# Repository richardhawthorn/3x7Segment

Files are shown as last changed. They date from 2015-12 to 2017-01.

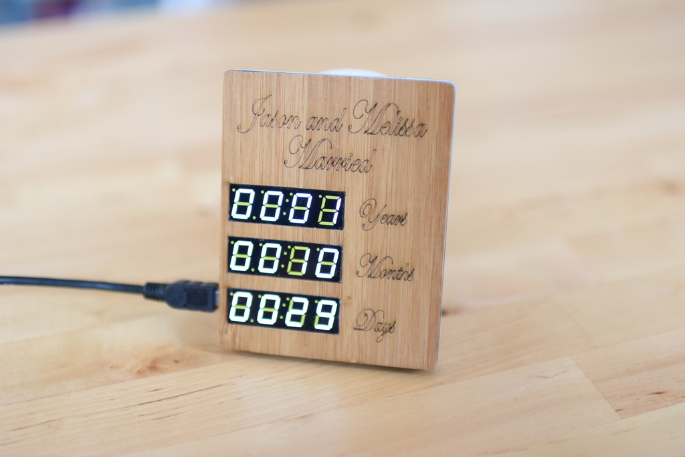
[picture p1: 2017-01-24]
images/DSC_3861.JPG

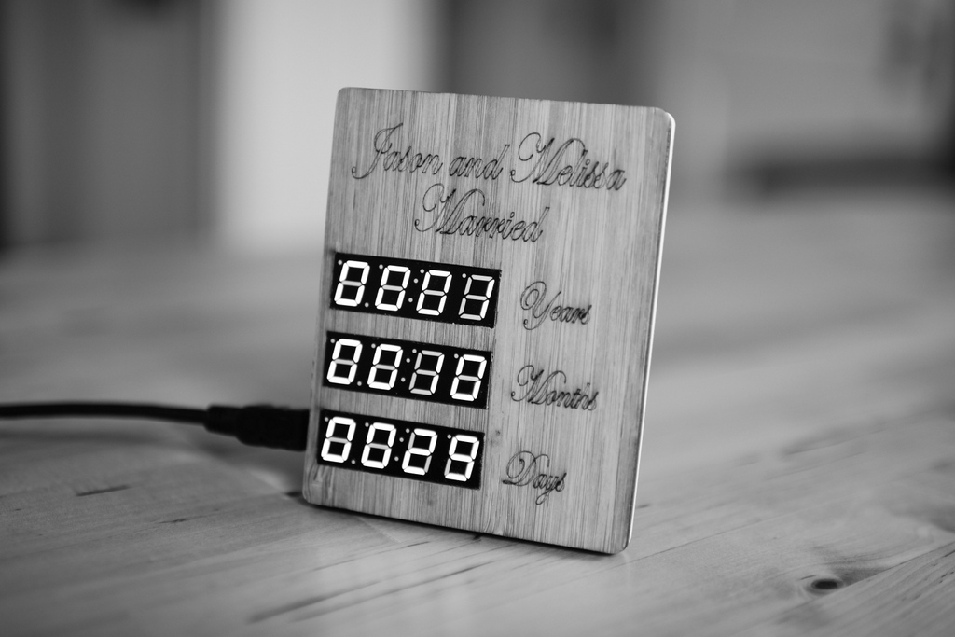
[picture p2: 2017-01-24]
images/16-DSC_3874.JPG

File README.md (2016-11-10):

### Features

- ESP8266 wifi processor
- 3 x 7 segment displays
- 3.3V operation
- Mini USB power connector
- FTDI chip and programming port

### License

This work is licensed under a Creative Commons Attribution-ShareAlike 4.0 International License.

<br />
Designed by <a xmlns:cc="http://creativecommons.org/ns#" href="http://www.richardhawthorn.com" property="cc:attributionName" rel="cc:attributionURL" target="_blank">Richard Hawthorn</a><br />
<a rel="license" href="http://creativecommons.org/licenses/by-sa/4.0/" target="_blank">View License</a>

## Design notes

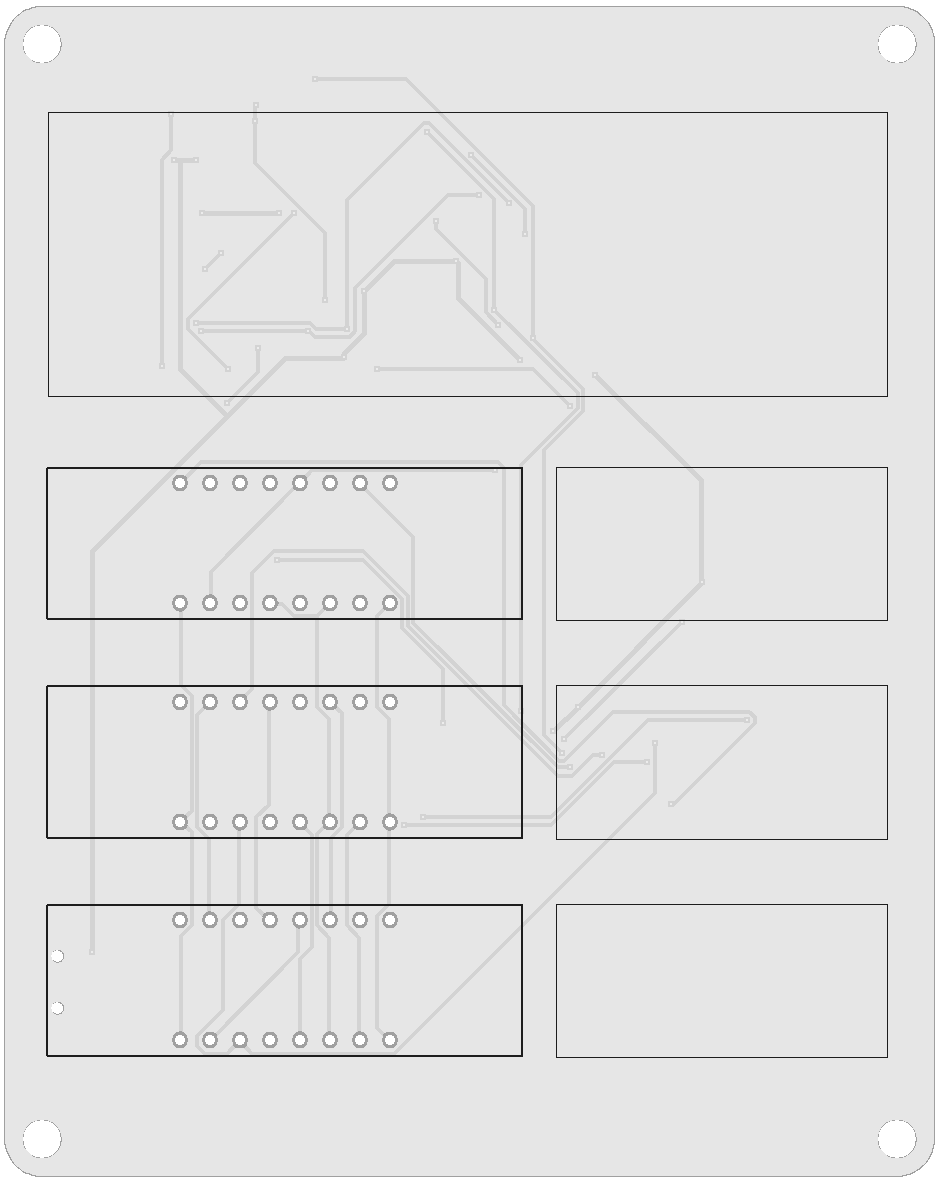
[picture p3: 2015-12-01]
images/pcb_back_v2.png

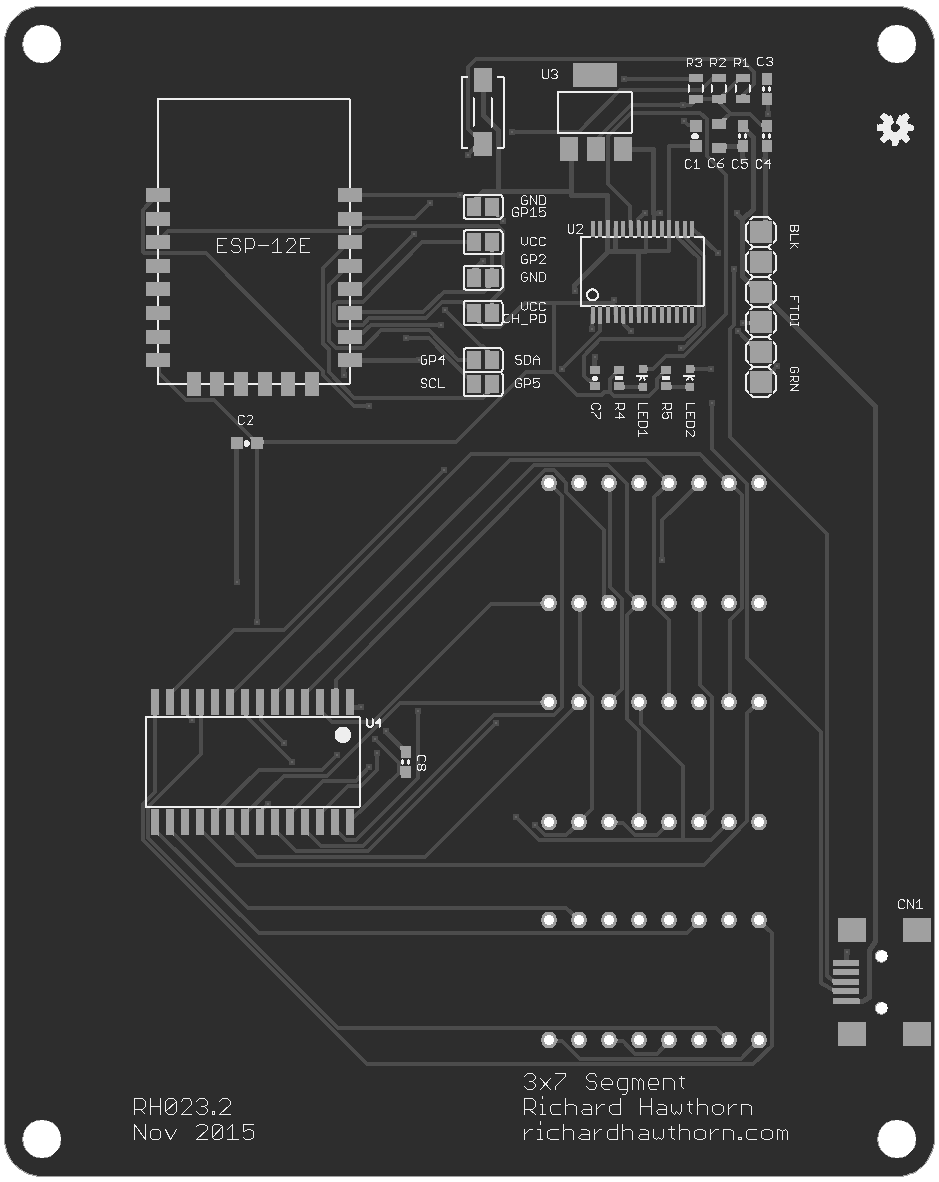
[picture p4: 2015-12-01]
images/pcb_front_v2_black.png

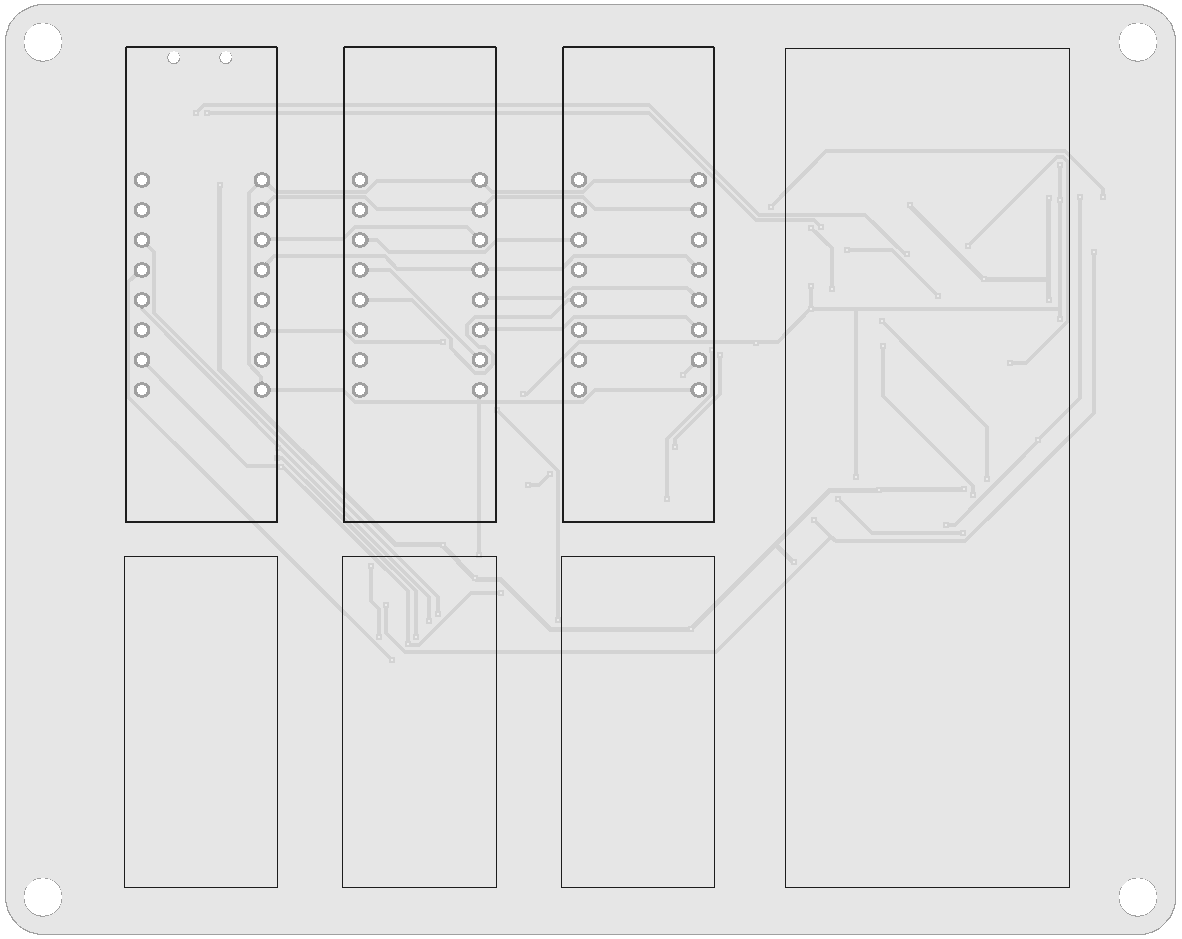
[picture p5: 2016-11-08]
images/pcb_back_v3.png

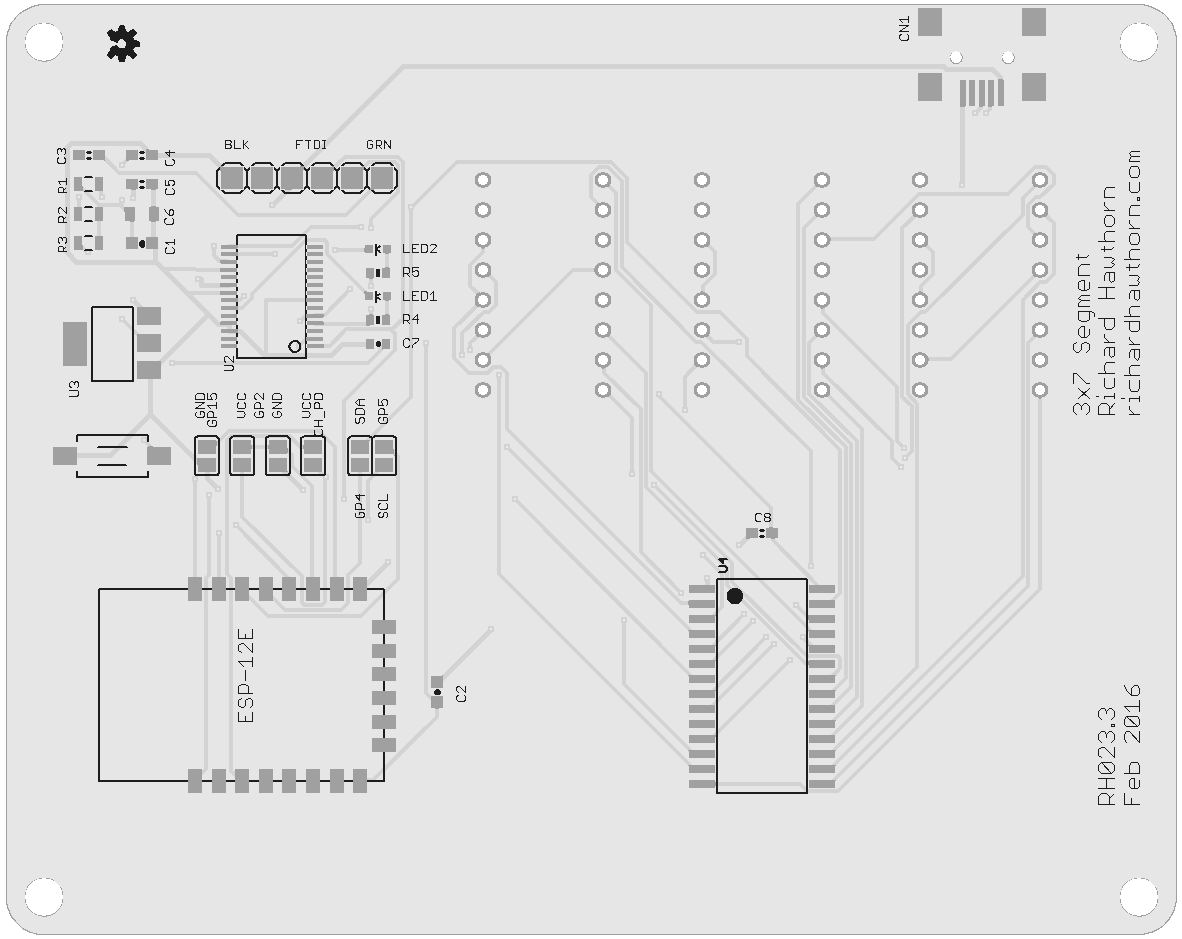
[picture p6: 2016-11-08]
images/pcb_front_v3.png

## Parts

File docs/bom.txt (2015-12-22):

Part     Value          Device 

C1       0.1uF          CAP0805-CAP 
C2       0.1uF          CAP0805-CAP 
C3       0.1uF          CAP0805-CAP 
C4       0.1uF          CAP0805-CAP 
C5       1uF            CAP0805-CAP 
C6       10uF           CAP0805-CAP 
C8       0.1uF          CAP0805-CAP 
CN1      USB            USB-MINI-B 
JP1      FTDI           PINHD-1X6 
LED3     7SEG-4DIGIT    7SEG-4DIGIT  
LED4     7SEG-4DIGIT    7SEG-4DIGIT 
LED5     7SEG-4DIGIT    7SEG-4DIGIT 
R1       4.7k           RESISTOR0805-RES 
R2       4.7k           RESISTOR0805-RES 
R3       4.7k           RESISTOR0805-RES 
S1       RESET          DTSM-3  
U1       ESP8266        ESP8266-ESP12E 
U3       REG1117        REG1117 
U4       HT16K33        HT16K33_SOP28

Future Upgrade

U2       FT232RLSSOP    FT232RLSSOP 
C7       0.1uF          CAP0805-CAP 
R4       1K             RESISTOR0402-RES 
R5       1K             RESISTOR0402-RES 
LED1     Red            LED0603 
LED2     Green          LED0603

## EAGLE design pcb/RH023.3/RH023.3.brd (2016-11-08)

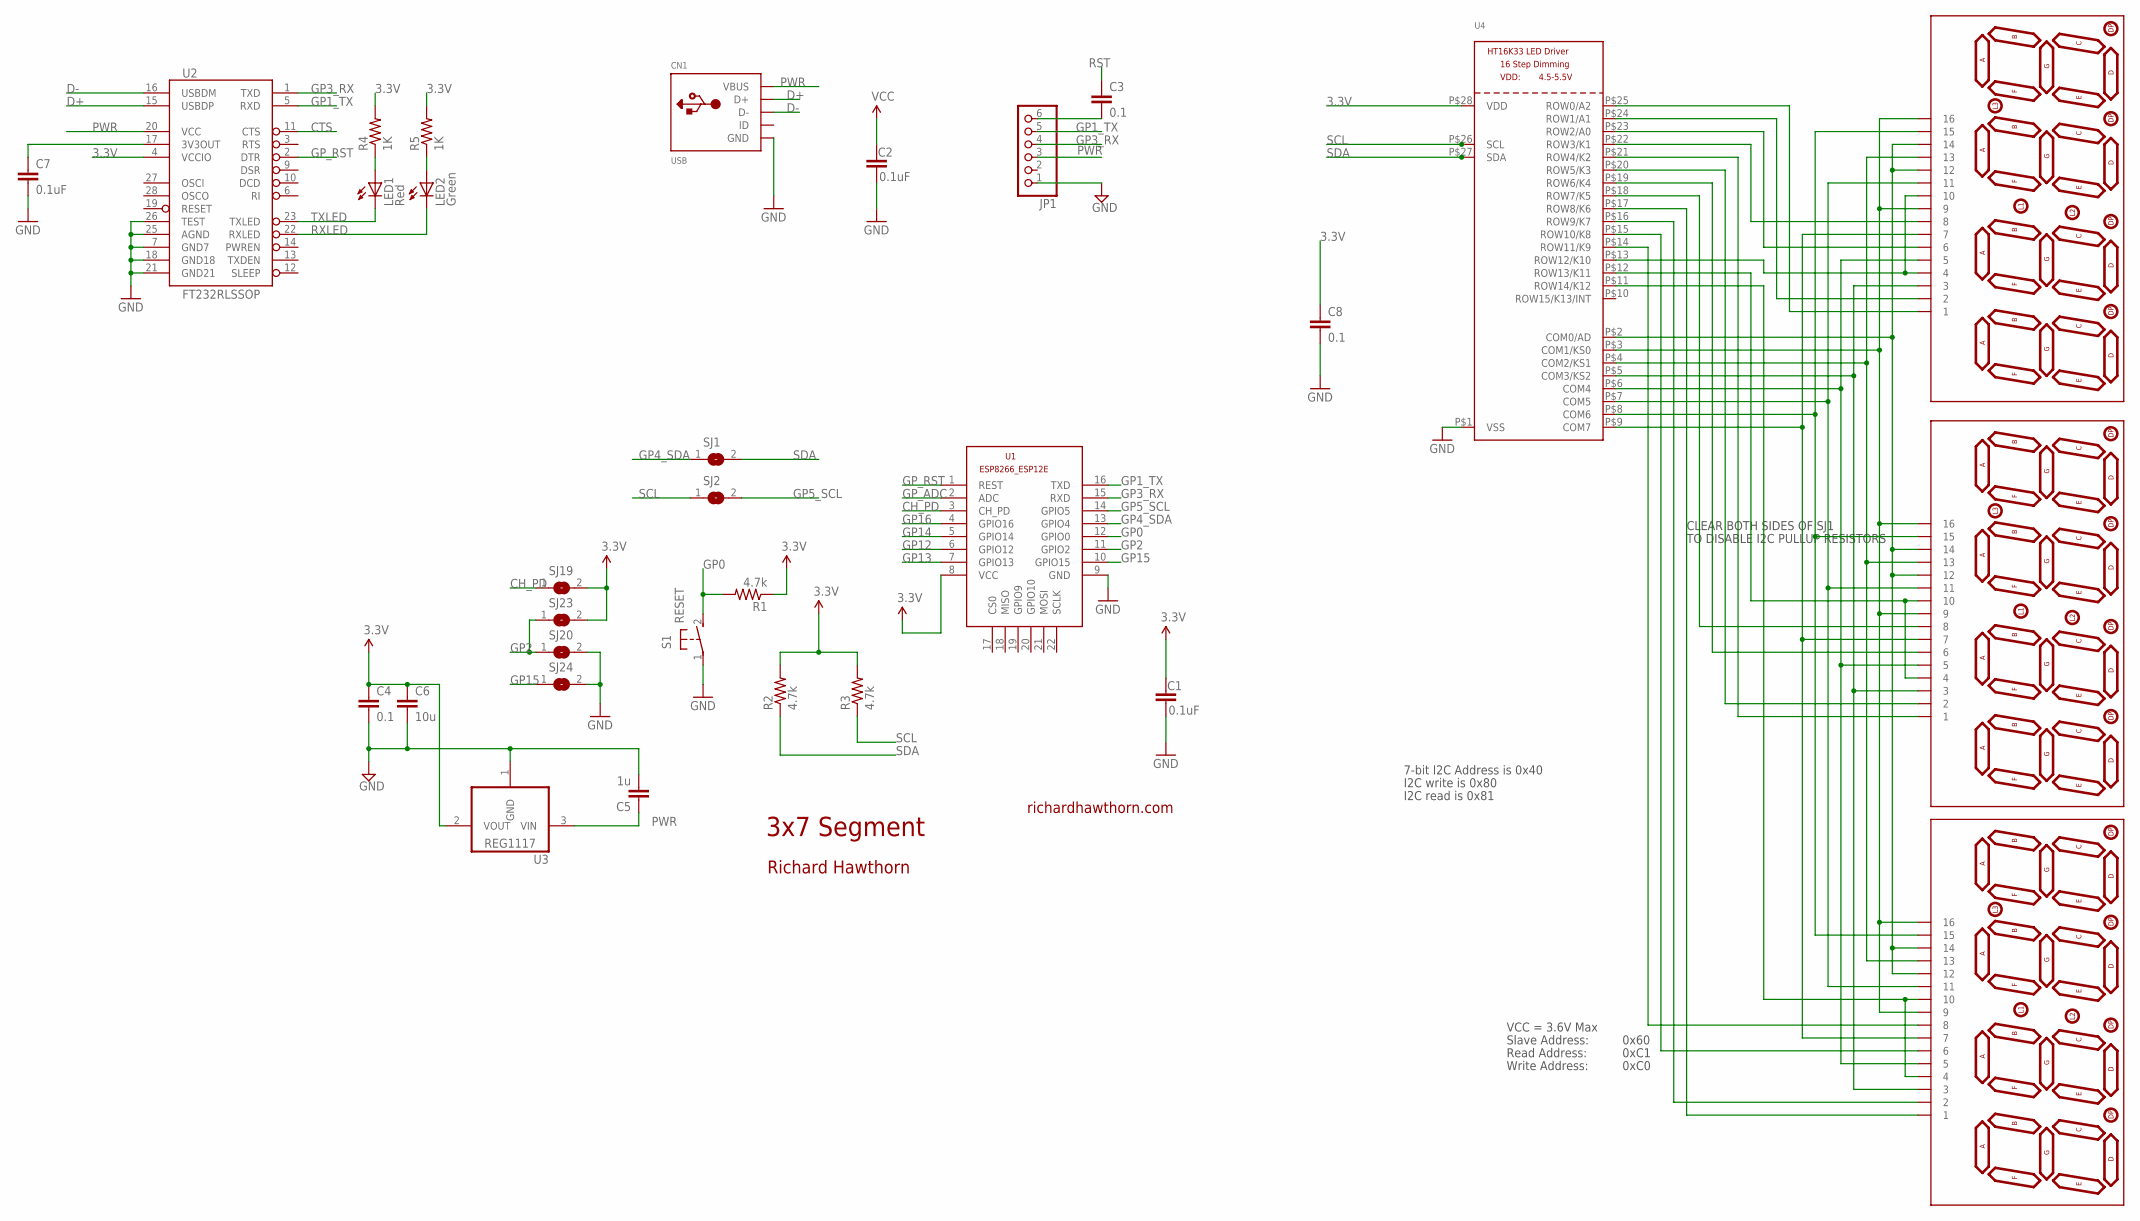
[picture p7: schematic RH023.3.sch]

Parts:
C1, C2: 0.1uF; 0603-CAP
C3, C4, C8: 0.1; 0603-CAP
C5: 1u; 0603-CAP
C6: 10u; 0805-CAP
C7: 0.1uF; 0402-CAP
CN1: USB; USB-MINIB
JP1: PINHD-1X6; 1X06
LED1: Red; LED-0603
LED2: Green; LED-0603
LED3, LED4, LED5: 7SEG-4DIGIT; SPARKFUN_7-SEGMENT-4DIGIT
R1, R2, R3: 4.7k; 0805
R4, R5: 1K; 0402-RES
S1: RESET; DTSM-3
SJ1, SJ2, SJ19, SJ20, SJ23, SJ24: SJ
U1: ESP8266-12EESP8266-ESP12E; ESP8266-ESP12E
U2: FT232RLSSOP; SSOP28DB
U3: REG1117; SOT223
U4: HT16K33_SOP28; SOP28_300MIL

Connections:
3.3V: C1.1, C2.1, C4.1, C6.1, C8.1, R1.1, R2.2, R3.2, R4.2, R5.2, SJ19.2, SJ23.2, U1.8 (VCC), U2.4 (VCCIO), U3.2 (VOUT), U4.P$28 (VDD)
3.3VOUT: C7.1, U2.17 (3V3OUT)
CH_PD: SJ19.1, U1.3 (CH_PD)
CTS: U2.11 (CTS)
D+: CN1.D+, U2.15 (USBDP)
D-: CN1.D-, U2.16 (USBDM)
GND: C1.2, C2.2, C4.2, C5.2, C6.2, C7.2, C8.2, CN1.GND, JP1.1, S1.1, SJ20.2, SJ24.2, U1.9 (GND), U2.7 (GND7), U2.18 (GND18), U2.21 (GND21), U2.25 (AGND), U2.26 (TEST), U3.1 (GND), U4.P$1 (VSS)
GP0: R1.2, S1.2, U1.12 (GPIO0)
GP1_TX: JP1.5, U1.16 (TXD), U2.5 (RXD)
GP2: SJ20.1, SJ23.1, U1.11 (GPIO2)
GP3_RX: JP1.4, U1.15 (RXD), U2.1 (TXD)
GP4_SDA: SJ1.1, U1.13 (GPIO4)
GP5_SCL: SJ2.2, U1.14 (GPIO5)
GP12: U1.6 (GPIO12)
GP13: U1.7 (GPIO13)
GP14: U1.5 (GPIO14)
GP15: SJ24.1, U1.10 (GPIO15)
GP16: U1.4 (GPIO16)
GP_ADC: U1.2 (ADC)
GP_RST: U1.1 (REST), U2.2 (DTR)
unnamed: LED3.12, LED3.14, LED4.12, LED4.14, LED5.12, LED5.14, U4.P$2 (COM0/AD)
unnamed: LED1.A, R4.1
unnamed: LED2.A, R5.1
unnamed: LED3.9, LED3.16, LED4.9, LED4.16, LED5.9, LED5.16, U4.P$3 (COM1/KS0)
unnamed: LED3.13, LED4.13, LED5.13, U4.P$4 (COM2/KS1)
unnamed: LED3.3, LED4.3, LED5.3, U4.P$5 (COM3/KS2)
unnamed: LED3.5, LED4.5, LED5.5, U4.P$6 (COM4)
unnamed: LED3.11, LED4.11, LED5.11, U4.P$7 (COM5)
unnamed: LED3.15, LED4.15, LED5.15, U4.P$8 (COM6)
unnamed: LED3.7, LED4.7, LED5.7, U4.P$9 (COM7)
unnamed: LED3.1, U4.P$25 (ROW0/A2)
unnamed: LED3.2, U4.P$24 (ROW1/A1)
unnamed: LED3.6, U4.P$23 (ROW2/A0)
unnamed: LED3.8, U4.P$22 (ROW3/K1)
unnamed: LED4.1, U4.P$21 (ROW4/K2)
unnamed: LED4.2, U4.P$20 (ROW5/K3)
unnamed: LED4.6, U4.P$19 (ROW6/K4)
unnamed: LED4.8, U4.P$18 (ROW7/K5)
unnamed: LED5.1, U4.P$17 (ROW8/K6)
unnamed: C3.2, JP1.6
unnamed: LED5.2, U4.P$16 (ROW9/K7)
unnamed: LED5.6, U4.P$15 (ROW10/K8)
unnamed: LED5.8, U4.P$14 (ROW11/K9)
unnamed: LED3.4, LED3.10, U4.P$13 (ROW12/K10)
unnamed: LED4.4, LED4.10, U4.P$12 (ROW13/K11)
unnamed: LED5.4, LED5.10, U4.P$11 (ROW14/K12)
PWR: C5.1, CN1.VBUS, JP1.3, U2.20 (VCC), U3.3 (VIN)
RST: C3.1
RXLED: LED2.C, U2.22 (RXLED)
SCL: R3.1, SJ2.1, U4.P$26 (SCL)
SDA: R2.1, SJ1.2, U4.P$27 (SDA)
TXLED: LED1.C, U2.23 (TXLED)

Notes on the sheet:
3x7 Segment
richardhawthorn.com
Richard Hawthorn
CLEAR BOTH SIDES OF SJ1
TO DISABLE I2C PULLUP RESISTORS
7-bit I2C Address is 0x40
I2C write is 0x80
I2C read is 0x81
VCC = 3.6V Max
Read Address:
Write Address:
Slave Address:
0x60
0xC1
0xC0

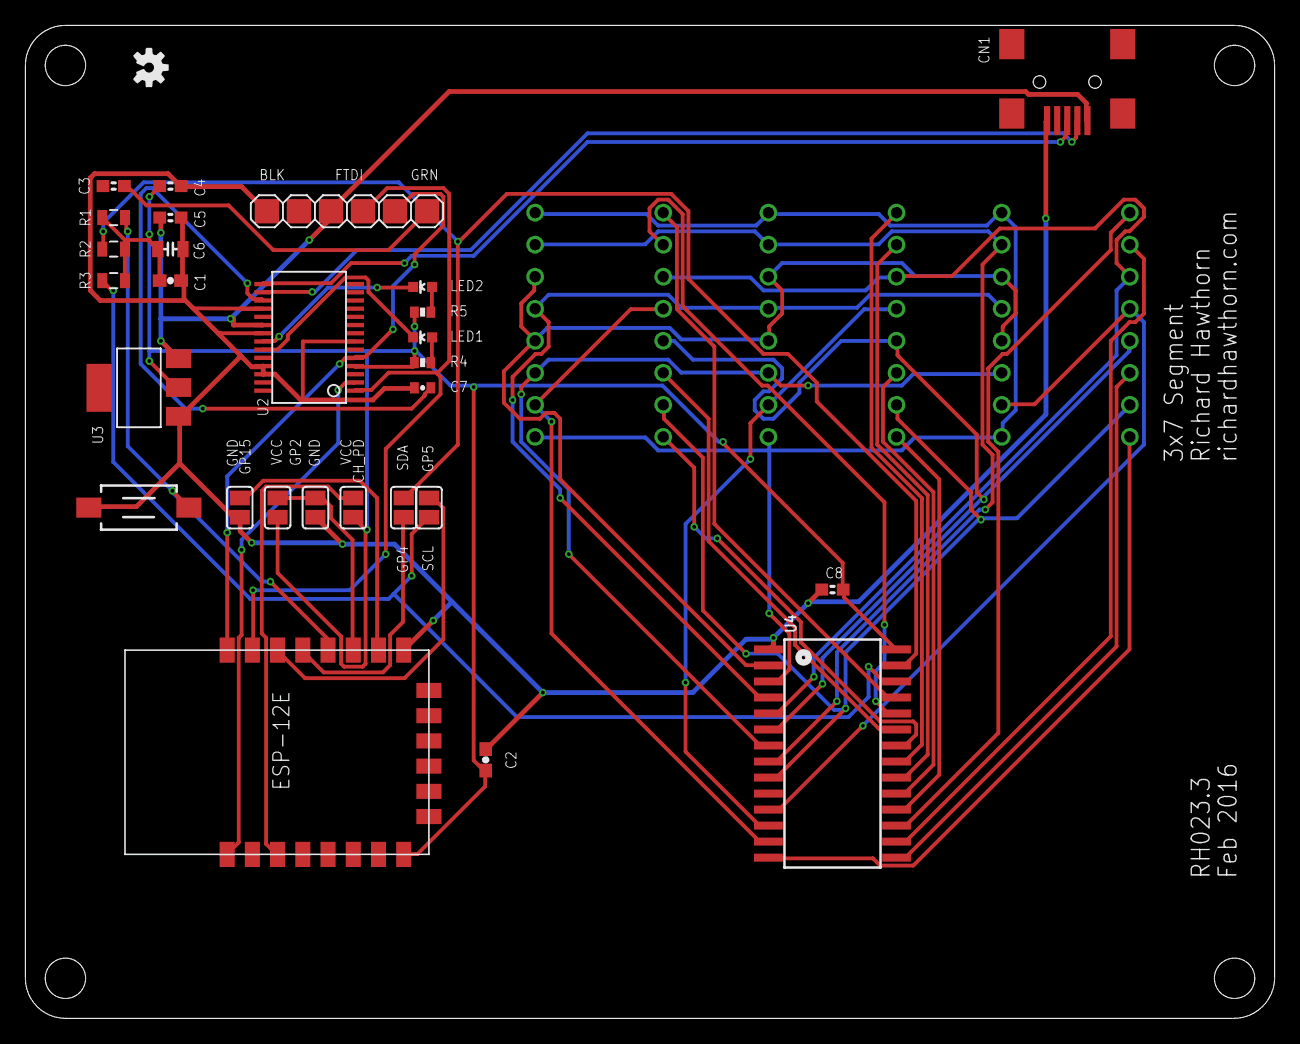
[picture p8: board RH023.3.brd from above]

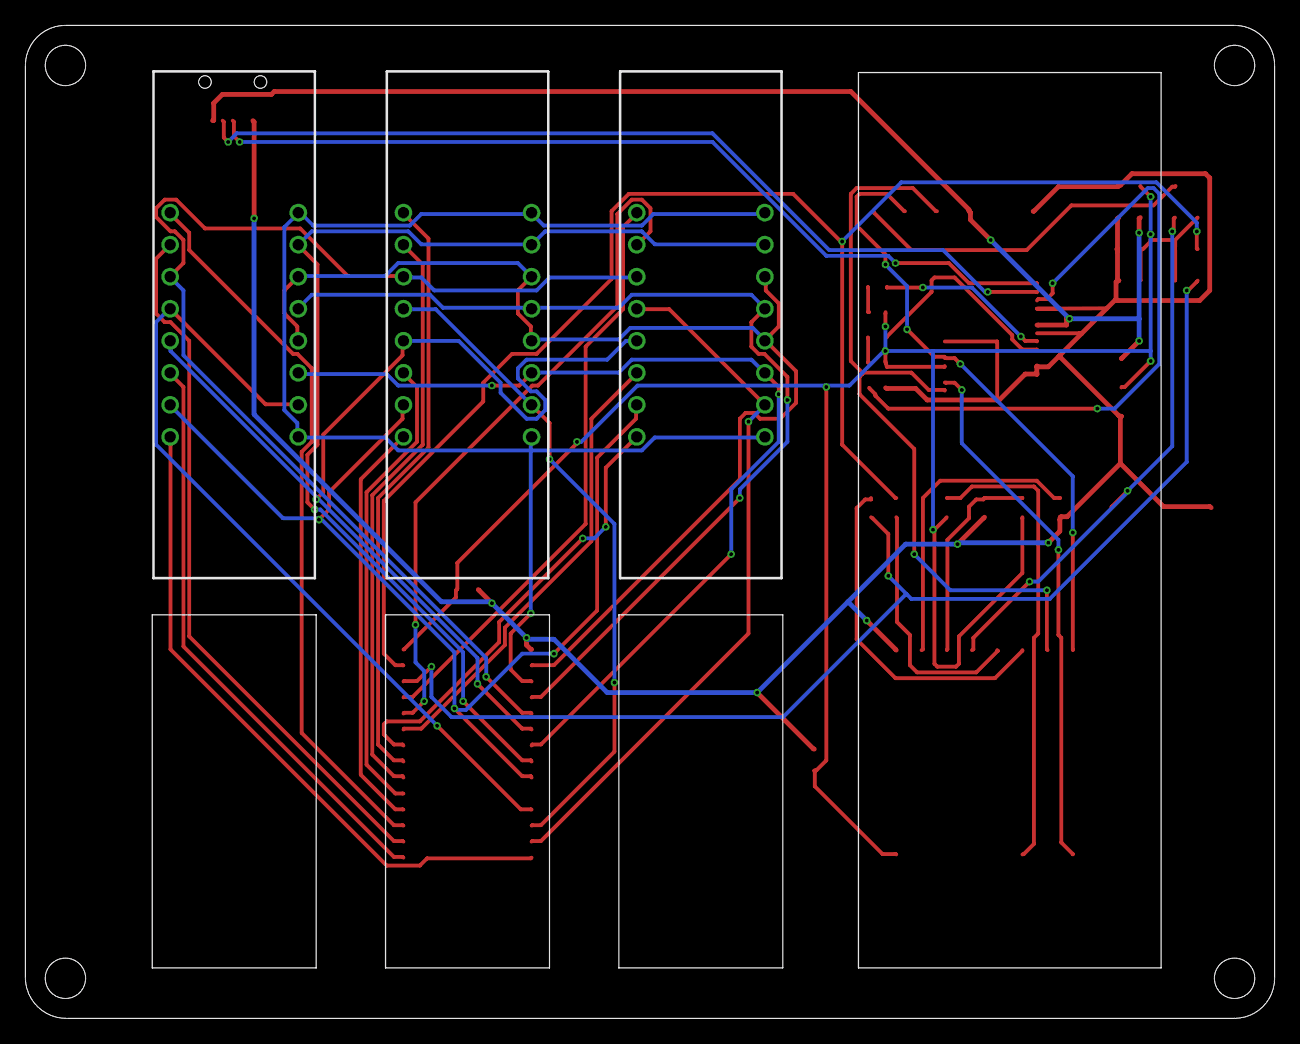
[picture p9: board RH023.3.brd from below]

Board: 2 copper layers, 99.1 x 78.7 mm, 32 parts (3 on the bottom side), 45 nets.

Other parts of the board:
U$3: OSHW-LOGO-S

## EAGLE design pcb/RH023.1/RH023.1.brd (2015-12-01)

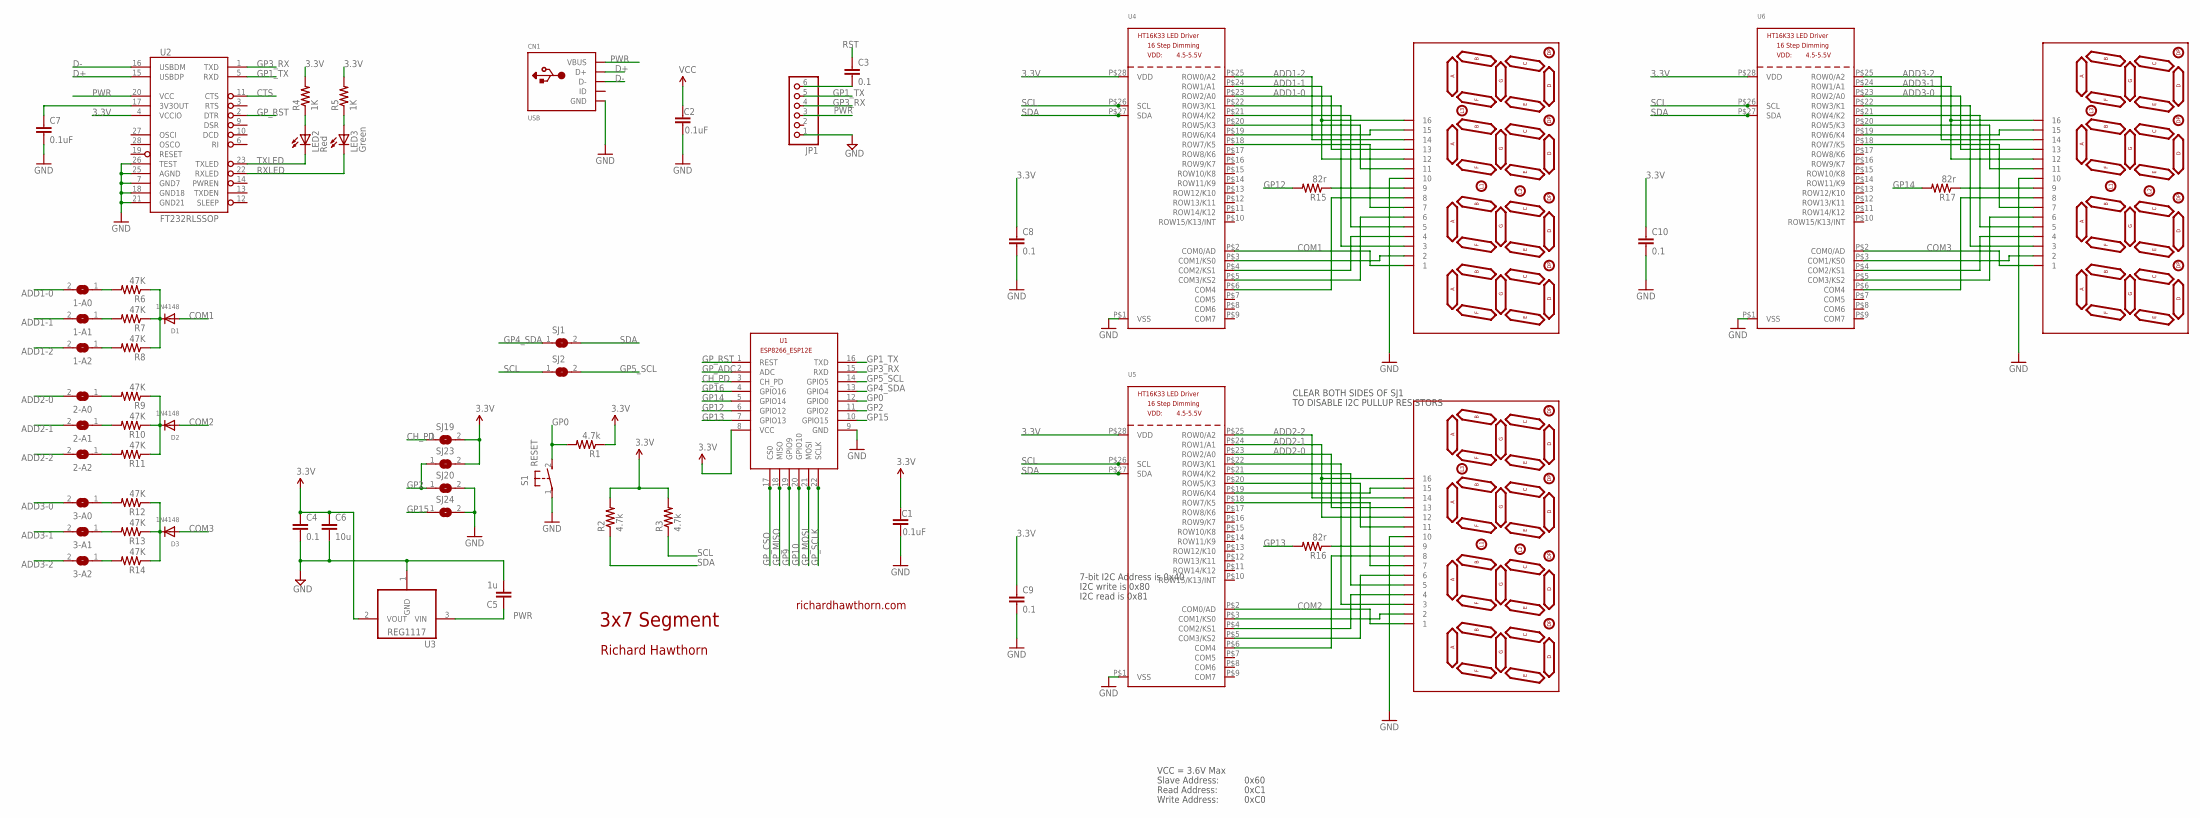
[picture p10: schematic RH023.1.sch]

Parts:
1-A0, 1-A1, 1-A2, 2-A0, 2-A1, 2-A2, 3-A0, 3-A1, 3-A2: SOLDERJUMPERREFLOW_NOPASTE; SOLDERJUMPER_REFLOW_NOPASTE
C1, C2: 0.1uF; 0603-CAP
C3, C4, C8, C9, C10: 0.1; 0603-CAP
C5: 1u; 0603-CAP
C6: 10u; 0805-CAP
C7: 0.1uF; 0402-CAP
CN1: USB; USB-MINIB
D1, D2, D3: 1N4148; SOD-323F
JP1: PINHD-1X6; 1X06
LED1, LED4, LED5: 7SEG-4DIGIT; SPARKFUN_7-SEGMENT-4DIGIT
LED2: Red; LED-0603
LED3: Green; LED-0603
R1, R2, R3: 4.7k; 0805
R4, R5: 1K; 0402-RES
R6, R7, R8, R9, R10, R11, R12, R13, R14: 47K; R0805
R15, R16, R17: 82r; 0805
S1: RESET; DTSM-3
SJ1, SJ2, SJ19, SJ20, SJ23, SJ24: SJ
U1: ESP8266-12EESP8266-ESP12E; ESP8266-ESP12E
U2: FT232RLSSOP; SSOP28DB
U3: REG1117; SOT223
U4, U5, U6: HT16K33_SOP28; SOP28_300MIL

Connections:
3.3V: C1.1, C2.1, C4.1, C6.1, C8.1, C9.1, C10.1, R1.1, R2.2, R3.2, R4.2, R5.2, SJ19.2, SJ23.2, U1.8 (VCC), U2.4 (VCCIO), U3.2 (VOUT), U4.P$28 (VDD), U5.P$28 (VDD), U6.P$28 (VDD)
3.3VOUT: C7.1, U2.17 (3V3OUT)
ADD1-0: 1-A0.2, LED1.13, U4.P$23 (ROW2/A0)
ADD1-1: 1-A1.2, LED1.12, LED1.16, U4.P$24 (ROW1/A1)
ADD1-2: 1-A2.2, LED1.14, U4.P$25 (ROW0/A2)
ADD2-0: 2-A0.2, LED4.13, U5.P$23 (ROW2/A0)
ADD2-1: 2-A1.2, LED4.12, LED4.16, U5.P$24 (ROW1/A1)
ADD2-2: 2-A2.2, LED4.14, U5.P$25 (ROW0/A2)
ADD3-0: 3-A0.2, LED5.13, U6.P$23 (ROW2/A0)
ADD3-1: 3-A1.2, LED5.12, LED5.16, U6.P$24 (ROW1/A1)
ADD3-2: 3-A2.2, LED5.14, U6.P$25 (ROW0/A2)
CH_PD: SJ19.1, U1.3 (CH_PD)
COM1: D1.A, LED1.1, U4.P$2 (COM0/AD)
COM2: D2.A, LED4.1, U5.P$2 (COM0/AD)
COM3: D3.A, LED5.1, U6.P$2 (COM0/AD)
CTS: U2.11 (CTS)
D+: CN1.D+, U2.15 (USBDP)
D-: CN1.D-, U2.16 (USBDM)
GND: C1.2, C2.2, C4.2, C5.2, C6.2, C7.2, C8.2, C9.2, C10.2, CN1.GND, JP1.1, LED1.10, LED4.10, LED5.10, S1.1, SJ20.2, SJ24.2, U1.9 (GND), U2.7 (GND7), U2.18 (GND18), U2.21 (GND21), U2.25 (AGND), U2.26 (TEST), U3.1 (GND), U4.P$1 (VSS), U5.P$1 (VSS), U6.P$1 (VSS)
GP0: R1.2, S1.2, U1.12 (GPIO0)
GP1_TX: JP1.5, U1.16 (TXD), U2.5 (RXD)
GP2: SJ20.1, SJ23.1, U1.11 (GPIO2)
GP3_RX: JP1.4, U1.15 (RXD), U2.1 (TXD)
GP4_SDA: SJ1.1, U1.13 (GPIO4)
GP5_SCL: SJ2.2, U1.14 (GPIO5)
GP9: U1.19 (GPIO9)
GP10: U1.20 (GPIO10)
GP12: R15.2, U1.6 (GPIO12)
GP13: R16.2, U1.7 (GPIO13)
GP14: R17.2, U1.5 (GPIO14)
GP15: SJ24.1, U1.10 (GPIO15)
GP16: U1.4 (GPIO16)
GP_ADC: U1.2 (ADC)
GP_CSO: U1.17 (CS0)
GP_MISO: U1.18 (MISO)
GP_MOSI: U1.21 (MOSI)
GP_RST: U1.1 (REST), U2.2 (DTR)
GP_SCLK: U1.22 (SCLK)
unnamed: LED1.9, R15.1
unnamed: LED2.A, R4.1
unnamed: LED3.A, R5.1
unnamed: 2-A1.1, R10.2
unnamed: 1-A0.1, R6.2
unnamed: LED1.11, U4.P$20 (ROW5/K3)
unnamed: LED1.2, U4.P$3 (COM1/KS0)
unnamed: LED1.4, U4.P$4 (COM2/KS1)
unnamed: LED1.6, U4.P$5 (COM3/KS2)
unnamed: LED1.8, U4.P$6 (COM4)
unnamed: LED1.3, U4.P$22 (ROW3/K1)
unnamed: LED1.5, U4.P$21 (ROW4/K2)
unnamed: 2-A0.1, R9.2
unnamed: LED1.7, U4.P$18 (ROW7/K5)
unnamed: LED1.15, U4.P$19 (ROW6/K4)
unnamed: D2.C, R9.1, R10.1, R11.1
unnamed: D1.C, R6.1, R7.1, R8.1
unnamed: 1-A2.1, R8.2
unnamed: 1-A1.1, R7.2
unnamed: C3.2, JP1.6
unnamed: 2-A2.1, R11.2
unnamed: 3-A1.1, R13.2
unnamed: 3-A0.1, R12.2
unnamed: D3.C, R12.1, R13.1, R14.1
unnamed: 3-A2.1, R14.2
unnamed: LED4.2, U5.P$3 (COM1/KS0)
unnamed: LED4.4, U5.P$4 (COM2/KS1)
unnamed: LED4.6, U5.P$5 (COM3/KS2)
unnamed: LED4.8, U5.P$6 (COM4)
unnamed: LED4.3, U5.P$22 (ROW3/K1)
unnamed: LED4.5, U5.P$21 (ROW4/K2)
unnamed: LED4.15, U5.P$19 (ROW6/K4)
unnamed: LED4.11, U5.P$20 (ROW5/K3)
unnamed: LED4.7, U5.P$18 (ROW7/K5)
unnamed: LED4.9, R16.1
unnamed: LED5.2, U6.P$3 (COM1/KS0)
unnamed: LED5.4, U6.P$4 (COM2/KS1)
unnamed: LED5.6, U6.P$5 (COM3/KS2)
unnamed: LED5.8, U6.P$6 (COM4)
unnamed: LED5.3, U6.P$22 (ROW3/K1)
unnamed: LED5.5, U6.P$21 (ROW4/K2)
unnamed: LED5.15, U6.P$19 (ROW6/K4)
unnamed: LED5.11, U6.P$20 (ROW5/K3)
unnamed: LED5.7, U6.P$18 (ROW7/K5)
unnamed: LED5.9, R17.1
PWR: C5.1, CN1.VBUS, JP1.3, U2.20 (VCC), U3.3 (VIN)
RST: C3.1
RXLED: LED3.C, U2.22 (RXLED)
SCL: R3.1, SJ2.1, U4.P$26 (SCL), U5.P$26 (SCL), U6.P$26 (SCL)
SDA: R2.1, SJ1.2, U4.P$27 (SDA), U5.P$27 (SDA), U6.P$27 (SDA)
TXLED: LED2.C, U2.23 (TXLED)

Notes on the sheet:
3x7 Segment
richardhawthorn.com
Richard Hawthorn
CLEAR BOTH SIDES OF SJ1
TO DISABLE I2C PULLUP RESISTORS
7-bit I2C Address is 0x40
I2C write is 0x80
I2C read is 0x81
VCC = 3.6V Max
Read Address:
Write Address:
Slave Address:
0x60
0xC1
0xC0

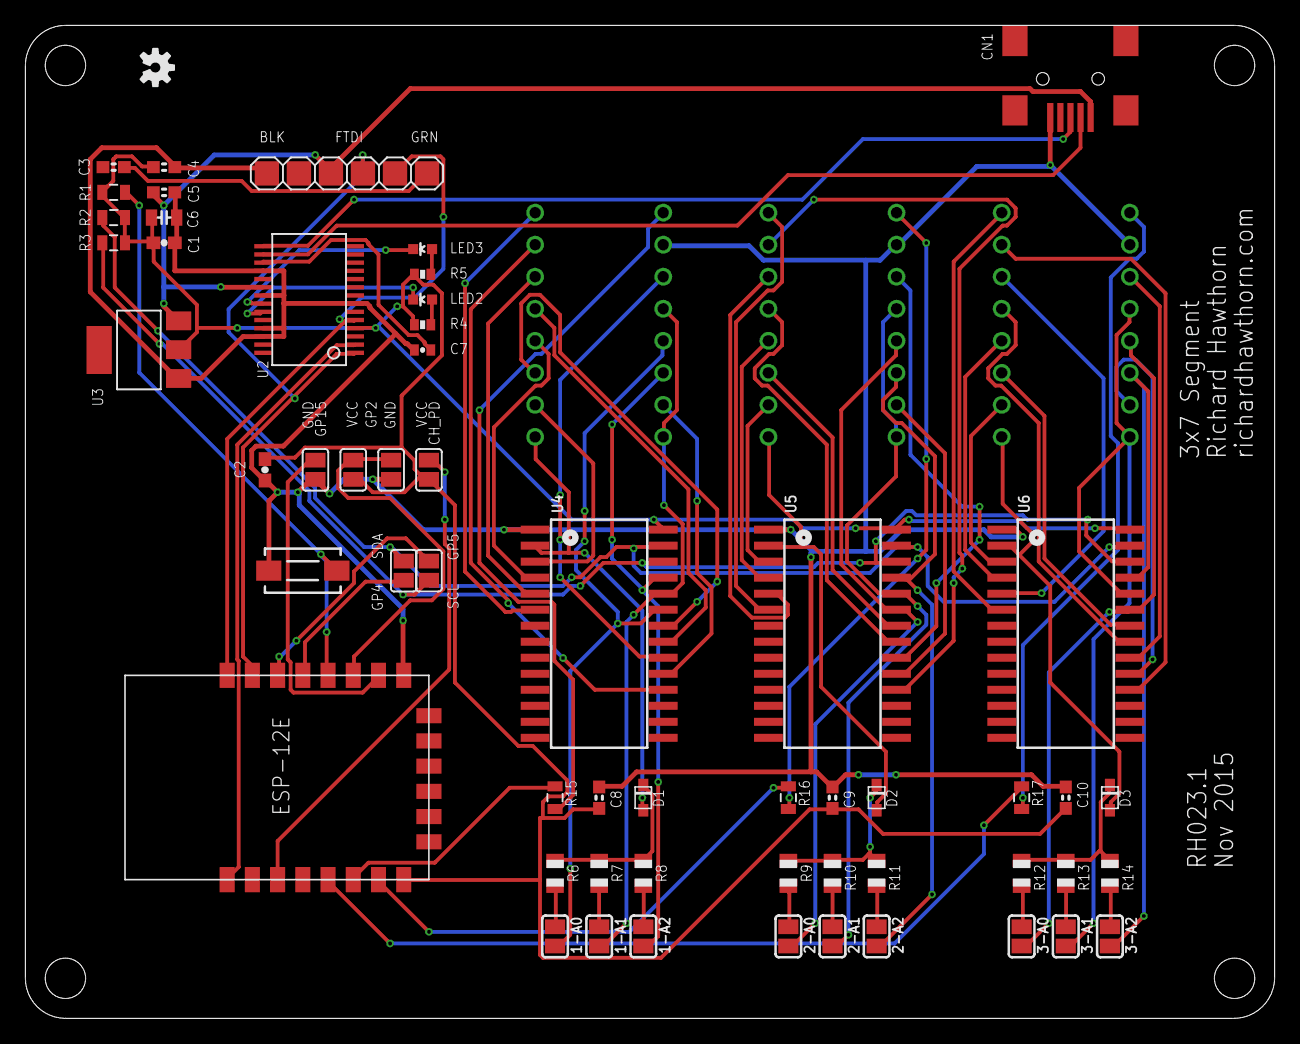
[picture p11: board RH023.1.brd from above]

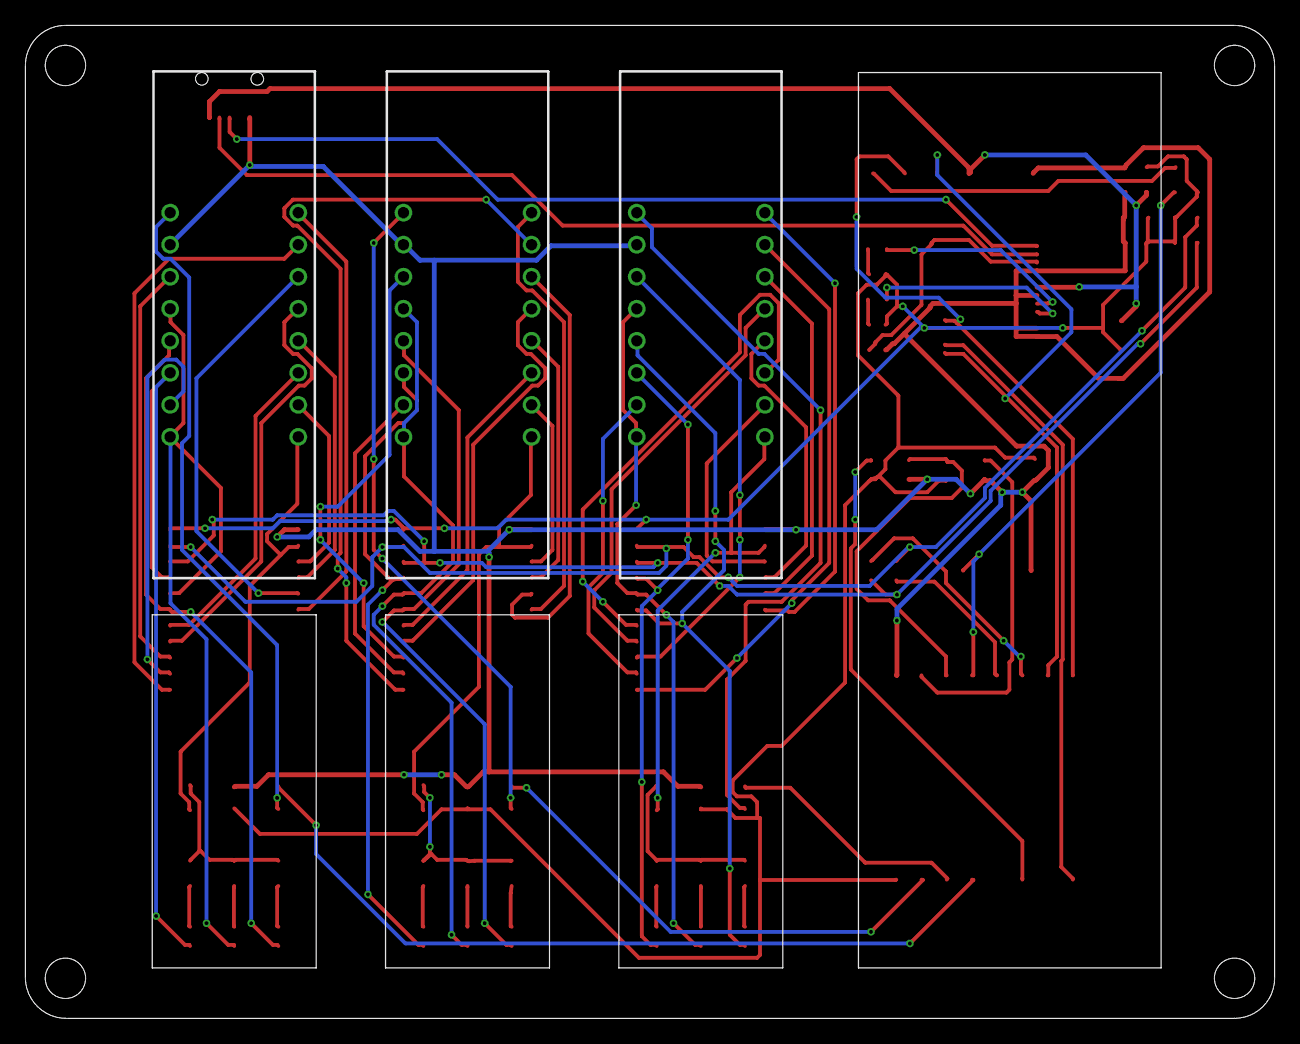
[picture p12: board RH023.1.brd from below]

Board: 2 copper layers, 99.1 x 78.7 mm, 60 parts (3 on the bottom side), 79 nets.

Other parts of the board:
U$3: OSHW-LOGO-S

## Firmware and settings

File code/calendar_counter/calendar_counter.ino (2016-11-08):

/*
 *  This sketch displays the difference between two dates on 3 x 7 segment led screens
 *
 */

#include <ESP8266WiFi.h>

#include <Wire.h>
#include <TimeLib.h>
#include "Adafruit_LEDBackpack.h"
#include "Adafruit_GFX.h"

Adafruit_LEDBackpack matrix = Adafruit_LEDBackpack();

// *******************************************************
//     Setup
// *******************************************************

const char* ssid     = "wifi_ssid";
const char* password = "wifi_password";
String compare_date = "2016-06-18";
int minutes_between_refresh = 30;

// *******************************************************
// *******************************************************

const char* host = "www.codenamefish.co.uk";
int sleep_minutes = 1;


void displayCharacter(int offset, int character, int number){

  offset = offset + 4 - character;
  
  if (number == 0){
    matrix.displaybuffer[0] |= 0x0001 << offset;
    matrix.displaybuffer[1] |= 0x0001 << offset;
    matrix.displaybuffer[2] |= 0x0001 << offset;
    matrix.displaybuffer[3] |= 0x0001 << offset;
    matrix.displaybuffer[4] |= 0x0001 << offset;
    matrix.displaybuffer[5] |= 0x0001 << offset;
  }

  if (number == 1){
    matrix.displaybuffer[4] |= 0x0001 << offset;
    matrix.displaybuffer[5] |= 0x0001 << offset;
  }

  if (number == 2){
    matrix.displaybuffer[0] |= 0x0001 << offset;
    matrix.displaybuffer[1] |= 0x0001 << offset;
    matrix.displaybuffer[3] |= 0x0001 << offset;
    matrix.displaybuffer[4] |= 0x0001 << offset;
    matrix.displaybuffer[6] |= 0x0001 << offset;
  }

  if (number == 3){
    matrix.displaybuffer[0] |= 0x0001 << offset;
    matrix.displaybuffer[3] |= 0x0001 << offset;
    matrix.displaybuffer[4] |= 0x0001 << offset;
    matrix.displaybuffer[5] |= 0x0001 << offset;
    matrix.displaybuffer[6] |= 0x0001 << offset;
  }

  if (number == 4){
    matrix.displaybuffer[2] |= 0x0001 << offset;
    matrix.displaybuffer[4] |= 0x0001 << offset;
    matrix.displaybuffer[5] |= 0x0001 << offset;
    matrix.displaybuffer[6] |= 0x0001 << offset;
  }

  if (number == 5){
    matrix.displaybuffer[0] |= 0x0001 << offset;
    matrix.displaybuffer[2] |= 0x0001 << offset;
    matrix.displaybuffer[3] |= 0x0001 << offset;
    matrix.displaybuffer[5] |= 0x0001 << offset;
    matrix.displaybuffer[6] |= 0x0001 << offset;
  }

  if (number == 6){
    matrix.displaybuffer[0] |= 0x0001 << offset;
    matrix.displaybuffer[1] |= 0x0001 << offset;
    matrix.displaybuffer[2] |= 0x0001 << offset;
    matrix.displaybuffer[3] |= 0x0001 << offset;
    matrix.displaybuffer[5] |= 0x0001 << offset;
    matrix.displaybuffer[6] |= 0x0001 << offset;
  }

  if (number == 7){
    matrix.displaybuffer[3] |= 0x0001 << offset;
    matrix.displaybuffer[4] |= 0x0001 << offset;
    matrix.displaybuffer[5] |= 0x0001 << offset;
  }

  if (number == 8){
    matrix.displaybuffer[0] |= 0x0001 << offset;
    matrix.displaybuffer[1] |= 0x0001 << offset;
    matrix.displaybuffer[2] |= 0x0001 << offset;
    matrix.displaybuffer[3] |= 0x0001 << offset;
    matrix.displaybuffer[4] |= 0x0001 << offset;
    matrix.displaybuffer[5] |= 0x0001 << offset;
    matrix.displaybuffer[6] |= 0x0001 << offset;
  }

  if (number == 9){
    matrix.displaybuffer[0] |= 0x0001 << offset;
    matrix.displaybuffer[2] |= 0x0001 << offset;
    matrix.displaybuffer[3] |= 0x0001 << offset;
    matrix.displaybuffer[4] |= 0x0001 << offset;
    matrix.displaybuffer[5] |= 0x0001 << offset;
    matrix.displaybuffer[6] |= 0x0001 << offset;
  }

}


void displayNumber(int screen, int number){

  int offset = (screen-1) * 4;

  displayCharacter(offset, 1, (number%10000)/1000);
  displayCharacter(offset, 2, (number%1000)/100);
  displayCharacter(offset, 3, (number%100)/10);
  displayCharacter(offset, 4, number%10);
    
}



void clearScreenBuffer(){

  matrix.displaybuffer[0] = 0x0000;
  matrix.displaybuffer[1] = 0x0000;
  matrix.displaybuffer[2] = 0x0000;
  matrix.displaybuffer[3] = 0x0000;
  matrix.displaybuffer[4] = 0x0000;
  matrix.displaybuffer[5] = 0x0000;
  matrix.displaybuffer[6] = 0x0000;
  matrix.displaybuffer[7] = 0x0000;
  
}

void writeToScreen(){
  matrix.writeDisplay();
}



void setup() {
  Serial.begin(115200);
  delay(10);
  
  Serial.println();
  Serial.print("Connecting to ");
  Serial.println(ssid);
  
  WiFi.begin(ssid, password);
  
  while (WiFi.status() != WL_CONNECTED) {
    delay(500);
    Serial.print(".");
  }

  Serial.println("");
  Serial.println("WiFi connected");  
  Serial.println("IP address: ");
  Serial.println(WiFi.localIP());

  matrix.begin(0x70);  // pass in the address

  displayNumber(1, 0);
  displayNumber(2, 0);
  displayNumber(3, 0);

  writeToScreen();
  
}

int value = 0;




void loop() {

  clearScreenBuffer();

  int counter = 0;
  String date = "";

  delay(5000);

  Serial.print("connecting to ");
  Serial.println(host);
  
  // Use WiFiClient class to create TCP connections
  WiFiClient client;
  const int httpPort = 80;
  if (!client.connect(host, httpPort)) {
    Serial.println("connection failed");
    return;
  }

  String url = "/compare_dates";
  url += "?date=";
  url += compare_date;
  url += "&timezone=";
  url += "EST";
  
  Serial.print("Requesting URL: ");
  Serial.println(url);
  
  // This will send the request to the server
  client.print(String("GET ") + url + " HTTP/1.1\r\n" +
               "Host: " + host + "\r\n" + 
               "User-Agent: runscope/0.1" + 
               "Connection: close\r\n\r\n");
  delay(5000);

  String line;
  
  // Read all the lines of the reply from server and print them to Serial
  while(client.available()){
    line = client.readStringUntil('\r');
    Serial.print(line);

    counter++;

    //if this is the line we want, save it into the date variable
    if (counter == 10){
      date = line;
    }
    
  }

  //if we have a date
  if (date != ""){
  
    String string_year = date.substring(1, 3);
    String string_month = date.substring(4, 6);
    String string_day = date.substring(7, 9);

    int int_year = string_year.toInt();
    int int_month = string_month.toInt();
    int int_day = string_day.toInt();

    //display our results
    displayNumber(1, int_year);
    displayNumber(2, int_month);
    displayNumber(3, int_day);
    writeToScreen();

    //once we have 1 good reading, we can revert to our main sleep time
    sleep_minutes = minutes_between_refresh;

  }

  //wait until we make the request again
  delay(60000 * sleep_minutes);
}

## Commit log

2015-12-01 first version of the pcb
    [RH023.1.brd, RH023.1.sch]
2015-12-01 second version, gerbers and images
    [RH023.2.brd, RH023.2.sch]
2015-12-01 fixed unattached nets
    [RH023.2.brd, RH023.2.sch]
2015-12-22 added a BOM
2016-11-08 add v3 of the pcb
    [RH023.3.brd, RH023.3.sch]
2016-11-08 Arduino code for v2 of the board

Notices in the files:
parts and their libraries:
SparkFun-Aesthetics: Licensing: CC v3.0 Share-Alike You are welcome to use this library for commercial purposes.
